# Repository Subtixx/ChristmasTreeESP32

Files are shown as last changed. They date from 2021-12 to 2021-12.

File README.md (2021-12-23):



<br />
<div align="center">
  <a href="https://github.com/othneildrew/Best-README-Template">
    
  </a>

  <h3 align="center">ChristmasTreeESP32</h3>

  <p align="center">
    A PCB Christmas tree using an ESP32 and 12 RGB LEDs
  </p>
</div>

<!-- TABLE OF CONTENTS -->
<details>
  <summary>Table of Contents</summary>
  <ol>
    <li><a href="#about-the-project">About The Project</a></li>
    <li><a href="#why-have-i-created-this">Why have I created this?</a></li>
    <li><a href="#pcb-preview">PCB Preview</a></li>
    <li><a href="#webpage-preview">Webpage Preview</a></li>
    <li><a href="#android-app">Android App</a></li>
    <li><a href="#wifi-setup">WiFi Setup</a></li>
    <li><a href="#issues-with-the-current-board">Issues with the current board</a></li>
  </ol>
</details>

<!-- ABOUT THE PROJECT -->
## About The Project

This is a christmas tree as PCB with RGB LEDs. It is controlled using an ESP32 and contains 12 RGB LEDs. Which can be configured in pairs of 2 so it has 6 different "zones" for colors.

The software can support up to 256 frames of animation (While a frame of animation is roughly 500ms long). The biggest animation I have tested had however only 20 frames.

**Before downloading the gerber files and ordering a PCB please take a look at [Issues with the current board](#issues-with-the-current-board), since this was my first ever PCB build I have made some mistake in the design which are outlined in the file linked above.**

The whole board was designed using EasyEDA. v2 will be designed in CircuitMaker if it will ever come out.
<p align="right">(<a href="#top">back to top</a>)</p>

# Why have I created this?

I know there are a number of soldering kits out there for a christmas tree as a PCB. However in my opinion those are lifeless and annoying. I had ordered one for christmas last year and it's not calming at all. The LEDs change color rapidly and in no order. 

I wanted a tree which looked more realistic, had the ability to change animations and could possibly also display several colors and not just red and green.

This is why I created a christmas tree PCB with an ESP32 and RGB LEDs.

<p align="right">(<a href="#top">back to top</a>)</p>

# PCB Preview

<table>
  <tr>
    <td>
      
      <br />
      Bottom View
    </td>
    <td>
      
      <br />
      Top View
    </td>
    <td>
      
      <br />
      Layout View
    </td>
  </tr>
</table>

<p align="right">(<a href="#top">back to top</a>)</p>

# Webpage Preview

_(Only frontend part is done)_



<p align="right">(<a href="#top">back to top</a>)</p>

# Android App

<table>
  <tr>
    <td>
      
      <br />
      Main view
    </td>
    <td>
      
      <br />
      Settings view
    </td>
    <td>
      
      <br />
      My files view
    </td>
  </tr>
</table>

<p align="right">(<a href="#top">back to top</a>)</p>

# WiFi Setup

1. Enter the SSID of your Wifi in [WiFiCredentials.h:1](https://github.com/Subtixx/ChristmasTreeESP32/blob/6ed7a89fb9c6c5deb8025a748663b42830a94d5e/esp32_code/WiFiCredentials.h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)
2. Enter the password of your Wifi in [WiFiCredentials.h:2](https://github.com/Subtixx/ChristmasTreeESP32/blob/6ed7a89fb9c6c5deb8025a748663b42830a94d5e/esp32_code/WiFiCredentials.h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)

<p align="right">(<a href="#top">back to top</a>)</p>

# Issues with the current board

**NOTE:** As I am no electronic engineer the PCB does look ugly and can contain some non-standard things. Also after placing the order with JLCPCB, I have discovered that the silkscreen of the RGB LEDs are cut off, woops my mistake. Also I could not figure out how to get rid of the ESP32 Silkscreen.

All issues should be fixed with this new version.

<del>
- No idea why but I thought the PCB would be much much bigger than it is. It's smaller than the commercial one I got for christmas last year from ebay which was a huge disappointment to me.

- I have not checked for the pinout of the ESP32... So I assume there are some reserved GPIO pins connected :/.

- Pin 35 is connected.. However Pin 35 cannot be an output.

- Some resistors are in series and not connected to the LED. Identified ones are:
  - Pin 17
- The used part for the ESP32 has the wrong footprint (atleast the one I bought AZDelivery ESP32).. It works when bending while soldering but it should be fixed.

- It is missing an LED on the top of the tree. It looks odd when having the tree turned on without one.

- I have not used any ground plane. No idea if this is critical or if this makes me stupid. But I've connected the grounds for all LEDs using traces. Thinking about this one after the fact makes me feel dumb.

- The slot on the trunk is too tight, PCBs are too thick to fit in there.

- Not an issue but a note on my design, I didn't want to "harm" the look and feel of the tree. This is why I have only populated the front side with components.

</del>

<p align="right">(<a href="#top">back to top</a>)</p>

# Technical explanation

A post request has to be made to http://[IPofESP]/post with a JSON Encoded body. An example animation would look like this:
```json
[
    [1, 0, 0, 0, 0],
    [2, 0, 0, 0, 0],
    [3, 0, 0, 0, 0],

    [4, 0, 0, 0, 0],
    [0, 0, 0, 0, 0]
]
```

It's a 2D Array with the first dimension being the frame of animation and the second being the color of a LED group.
So in this example its a 5 frame animation (2.5 seconds long as one frame takes roughly 500 ms). With the following values
1. Red
2. Green
3. Blue
4. Yellow
5. Off

<p align="right">(<a href="#top">back to top</a>)</p>

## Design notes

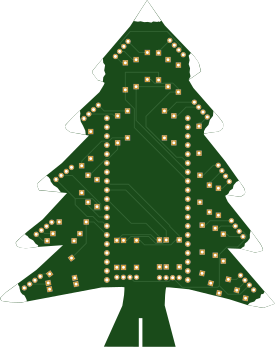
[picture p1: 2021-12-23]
flutter/assets/tree.png

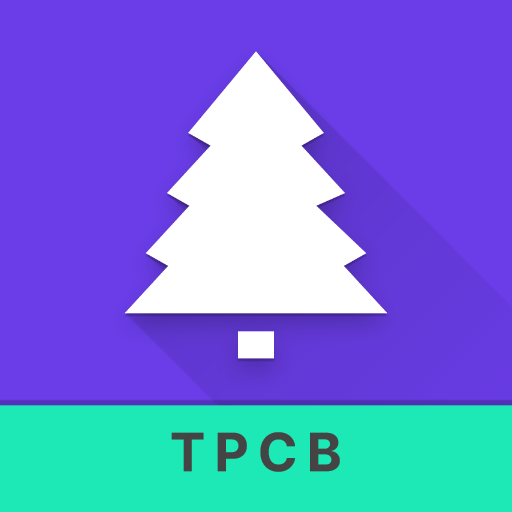
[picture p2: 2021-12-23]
flutter/assets/ic_launcher.png

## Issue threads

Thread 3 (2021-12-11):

Flutter: Saving animations to storage

Subtixx, 2021-12-11:
Currently when you close the app, your animation is gone. We should probably save the animation to storage.

Subtixx, 2021-12-12:
Implemented in version 1.2.0 of the app. Will upload code shortly.

Closed 2021-12-13.

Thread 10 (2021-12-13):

Board: Fix slot for PCB as base

Subtixx, 2021-12-13:
The slot on the trunk is far too thin.

Closed 2021-12-23.

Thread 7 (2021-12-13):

Board: Fix wrong GPIO pins

Subtixx, 2021-12-13:
Fix all the PINs that are connected wrong. For example GPIO35 which can only be an input.

Closed 2021-12-23.

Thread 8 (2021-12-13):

Board: Fix resistor connections

Subtixx, 2021-12-13:
Fix all connections to resistors which were connected in series rather than in parallel. Which also makes some LEDs not have a resistor at all.

Closed 2021-12-23.

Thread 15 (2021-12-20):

Flutter: Right side buttons don't work

Subtixx, 2021-12-20:
Issue is in this line. It has to be `startIndex + i`

https://github.com/Subtixx/ChristmasTreeESP32/blob/2c6fa35a4a4d65136beefa9ca0f90814443fd0c9/flutter/lib/screens/tree_widget.dart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

Closed 2021-12-20.

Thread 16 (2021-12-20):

Flutter: UI is cluttered and needs coherent design

Subtixx, 2021-12-20:
The UI is absolutely horrible. Until you know which buttons do what the buttons are confusing. The main page is far too full.

Ex:

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

When a file is loaded this gets even bigger issue:

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

Subtixx, 2021-12-24:
UI could look more like this:
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

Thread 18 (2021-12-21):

ESP32: Create endpoint to retrieve current animation

Subtixx, 2021-12-21:
Add an endpoint to retrieve the current animation in the memory of the ESP32

Subtixx, 2021-12-21:
Fixed in 9b67298a64a66f8290f6f9c816212080ef999234

Closed 2021-12-21.

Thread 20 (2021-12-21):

ESP32: Abort current animation when upload is received

Subtixx, 2021-12-21:
Currently it will just replace the current animation. This could lead to a fatal crash if the following comes true:

Current animation is 32 Frames long. We're in frame 24. Now an upload arrives with a new animation but only totaling 10 frames. The Arduino is trying to read frame 25 but we now only have 10 frames.

Subtixx, 2021-12-21:
One fix for this would be to only save a copy of the animation data. And on each new loop tick copy that into the actual animation buffer.

Downside on this though is double the memory requirements.

Subtixx, 2021-12-21:
Maybe the easiest fix would be a global boolean `hasChanged` which get set to `true` when new data arrives.

In the for loop we check this new bool and if it is true we break out of the for loop and set the `hasChanged` to `false`.

Closed 2021-12-21.

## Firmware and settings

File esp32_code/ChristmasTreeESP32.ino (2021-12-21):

// This should contain 2 defines for WIFI_SSID and WIFI_PASS
#include "WiFiCredentials.h"

#include <WiFi.h>
#include <ESPAsyncWebServer.h>
#include <ArduinoJson.h>
#include <StreamUtils.h>

//#define DEBUG 1

unsigned short eepRomSize = 512;

AsyncWebServer server(80);

byte rowSetup[][3] = {
  {32, 33, 25},
  {26, 27, 14},
};

ushort frameCount = 0;
unsigned char **frames;

// Boolean to specify if the animation has changed
bool hasChanged = false;

short blue[] = {
  33, // TOP
  4, // MIDDLE LEFT
  25, // MIDDLE RIGHT
  15, // BOTTOM LEFT
  12, // BOTTOM RIGHT
  5, // MIDDLE BOTTOM
};

short green[] = {
  32, // TOP
  16, // MIDDLE LEFT
  26, // MIDDLE RIGHT
  2, // BOTTOM LEFT
  14, // BOTTOM RIGHT
  18, // MIDDLE BOTTTOM
};

short red[] = {
  21, // TOP
  17, // MIDDLE LEFT
  27, // MIDDLE RIGHT
  0, // BOTTOM LEFT
  13, // BOTTOM RIGHT
  19, // MIDDLE BOTTOM
};

String strColors[5] = { "OFF", "RED", "GREEN", "BLUE", "YELLOW" };

// 0, 1, 2, 3, 4, 5
// TOP, MIDDLE LEFT, MIDDLE RIGHT, BOTTOM LEFT, BOTTOM RIGHT, MIDDLE BOTTOM

// New layout:
// Frames 1 - 256
// Rows 1 - 5 (eg Bands)
// Color 0 - 4 (eg Off, Red, Green, Blue, Yellow)

#pragma region WiFi Connection
// Code in here is just for the connection to your WiFi
void ConnectToWiFi()
{
  Serial.println();
  Serial.println();
  Serial.print("Connecting to ");
  Serial.println(WIFI_SSID);

  // WIFI Station => Make connection to AP
  WiFi.mode(WIFI_STA);
  WiFi.begin(WIFI_SSID, WIFI_PASS);

  while (WiFi.status() != WL_CONNECTED)
  {
    delay(500);
    Serial.print(".");
  }

  Serial.println("");
  Serial.println("WiFi connected");
  Serial.println("IP address: ");
  Serial.println(WiFi.localIP());
}
#pragma endregion

#pragma region Not Found Page
void notFound(AsyncWebServerRequest *request) {
  request->send(404, "text/plain", "Not found");
}
#pragma endregion

void setup()
{
  Serial.begin(115200);
  EEPROM.begin(512);
  delay(10);

  // This setups all the pins as outputs
  for (int i = 0; i < sizeof(red) / sizeof * (red); i++)
  {
    pinMode(red[i], OUTPUT);
    digitalWrite(red[i], LOW);
  }

  for (int i = 0; i < sizeof(green) / sizeof * (green); i++)
  {
    pinMode(green[i], OUTPUT);
    digitalWrite(green[i], LOW);
  }

  for (int i = 0; i < sizeof(blue) / sizeof * (blue); i++)
  {
    pinMode(blue[i], OUTPUT);
    digitalWrite(blue[i], LOW);
  }

  delay(10);
  ConnectToWiFi();

  DynamicJsonDocument doc(4096);
  EepromStream eepromStream(0, eepRomSize);
  deserializeJson(doc, eepromStream);

  JsonArray jsonFrames = doc.as<JsonArray>();
  if (frames != NULL)
  {
    for (int i = 0; i < frameCount; ++i)
    {
      delete[] frames[i];
    }
    delete[] frames;
  }

  frameCount = jsonFrames.size();
  frames = new unsigned char *[frameCount];
  for (int i = 0; i < frameCount; ++i)
    frames[i] = new unsigned char[6] {0};

  for (size_t i = 0; i < jsonFrames.size(); i++)
  {
    JsonArray bands = jsonFrames[i];
    // TOP
    frames[i][0] = bands[0].as<unsigned char>();

    // MIDDLE LEFT
    frames[i][1] = bands[1].as<unsigned char>();

    // MIDDLE RIGHT
    frames[i][2] = bands[2].as<unsigned char>();

    // BOTTOM LEFT
    frames[i][3] = bands[3].as<unsigned char>();

    // BOTTOM RIGHT
    frames[i][4] = bands[4].as<unsigned char>();

    // MIDDLE BOTTOM
    frames[i][5] = bands[5].as<unsigned char>();
  }

  server.on(
    "/get",
    HTTP_GET,
    [](AsyncWebServerRequest * request)
  {
#ifdef DEBUG
    Serial.println("Got get request!");
#endif
    String result = "[";
    for (int i = 0; i < frameCount; ++i)
    {
      String frame = String(frames[i][0]) + ", " +
                     String(frames[i][1]) + ", " +
                     String(frames[i][2]) + ", " +
                     String(frames[i][3]) + ", " +
                     String(frames[i][4]) + ", " +
                     String(frames[i][5]);

      result += "[" + frame + "]";
      if (i < frameCount - 1)
        result += ",";
    }
    result += "]";
    request->send(200, "application/json", result);
  });

  server.on(
    "/post",
    HTTP_POST,
  [](AsyncWebServerRequest * request) {},
  NULL,
  [](AsyncWebServerRequest * request, uint8_t *data, size_t len, size_t index, size_t total)
  {
#ifdef DEBUG
    Serial.write("Got data: ");
    for (size_t i = 0; i < len; i++)
    {
      Serial.write(data[i]);
    }
    Serial.println();
#endif

    DynamicJsonDocument doc(4096);
    DeserializationError err = deserializeJson(doc, data);
    if (err)
    {
      Serial.println("deserializeJson() failed with code " + String(err.f_str()));

      request->send(500, "application/json", "{\"result\": 1, \"msg\": \"" + String(err.f_str()) + "\"}");
      return;
    }

    EepromStream eepromStream(0, eepRomSize);
    serializeJson(doc, eepromStream);
    eepromStream.flush();

    // all frames of animations
    JsonArray jsonFrames = doc.as<JsonArray>();

#ifdef DEBUG
    Serial.println("Got " + String(jsonFrames.size()) + " frames of animation.");
#endif

    if (frames != NULL)
    {
      for (int i = 0; i < frameCount; ++i)
      {
        delete[] frames[i];
      }
      delete[] frames;
    }

    frameCount = jsonFrames.size();
    frames = new unsigned char *[frameCount];
    for (int i = 0; i < frameCount; ++i)
      frames[i] = new unsigned char[6] {0};

    for (size_t i = 0; i < jsonFrames.size(); i++)
    {
      JsonArray bands = jsonFrames[i];
      if (bands.size() < 6)
      {
        frameCount = 1;
        frames = new unsigned char *[frameCount];
        for (int i = 0; i < frameCount; ++i)
          frames[i] = new unsigned char[6] {0};

        request->send(200, "application/json", "{\"result\": 1, \"msg\": \"Too few band colors.\"}");
        return;
      }

      // TOP
      frames[i][0] = bands[0].as<unsigned char>();

      // MIDDLE LEFT
      frames[i][1] = bands[1].as<unsigned char>();

      // MIDDLE RIGHT
      frames[i][2] = bands[2].as<unsigned char>();

      // BOTTOM LEFT
      frames[i][3] = bands[3].as<unsigned char>();

      // BOTTOM RIGHT
      frames[i][4] = bands[4].as<unsigned char>();

      // MIDDLE BOTTOM
      frames[i][5] = bands[5].as<unsigned char>();
    }

    hasChanged = true;

    request->send(200, "application/json", "{\"result\": 0}");
  });
  server.onNotFound(notFound);
  server.begin();
}

void loop()
{
  if (frameCount == 0)
  {
    delay(500);
    return;
  }

  for (size_t i = 0; i < frameCount; i++)
  {
    if (hasChanged)
    {
      hasChanged = false;
      break;
    }
#ifdef DEBUG
    Serial.print("Frame ");
    Serial.print(i);
    Serial.print(": ");
    Serial.println();
    Serial.println("\t" + strColors[frames[i][0]]);
    Serial.println(strColors[frames[i][1]] + "\t\t" + strColors[frames[i][2]]);
    Serial.println(strColors[frames[i][3]] + "\t\t" + strColors[frames[i][4]]);
    Serial.println("\t" + strColors[frames[i][5]]);
#endif

    for (size_t j = 0; j < 6; j++)
    {
      digitalWrite(red[j], (frames[i][j] == 1 || frames[i][j] == 4) ? HIGH : LOW);
      digitalWrite(green[j], (frames[i][j] == 2 || frames[i][j] == 4) ? HIGH : LOW);
      digitalWrite(blue[j], (frames[i][j] == 3) ? HIGH : LOW);
    }
    delay(500);
  }

#ifdef DEBUG
  Serial.println("-------------------------");
#endif

  if (frameCount == 1)
  {
    for (int i = 0; i < 10; i++)
    {
      if (hasChanged)
      {
        hasChanged = false;
        break;
      }
      delay(500);
    }
  }
}

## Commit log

2021-12-03 Version 0.1 of the gerber files
    [Gerber_BoardOutline.GKO, Gerber_BottomLayer.GBL, Gerber_BottomSilkLayer.GBO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]
2021-12-03 Create ChristmasTreeESP32.ino
    Just a test version with breadboard until the PCB arrives!
2021-12-13 Update ESP32 code
2021-12-21 Fix #20 (ESP32: Abort current animation when upload is received)
    [ChristmasTreeESP32.ino]
2021-12-21 Add endpoint for getting current animation
2021-12-21 Fix #19 (ESP32: Persistent animation storage)
    [ChristmasTreeESP32.ino]
2021-12-23 PCB Fixes
    Fix #10 (Board: Fix slot for PCB as base)
    Fix #9 (Board: Add tree top LED)
    Fix #8 (Board: Fix resistor connections)
    Fix #7 (Board: Fix wrong GPIO pins)
    [Gerber_BoardOutline.GKO, Gerber_BottomLayer.GBL, Gerber_BottomSilkLayer.GBO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]
